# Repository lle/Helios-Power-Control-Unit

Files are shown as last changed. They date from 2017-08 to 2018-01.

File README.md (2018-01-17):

# Helios Makerspace - PCU: Power Control Unit

## Short Description
Device that request a keycode from the user in order to power-up a tool in a Makerspace  
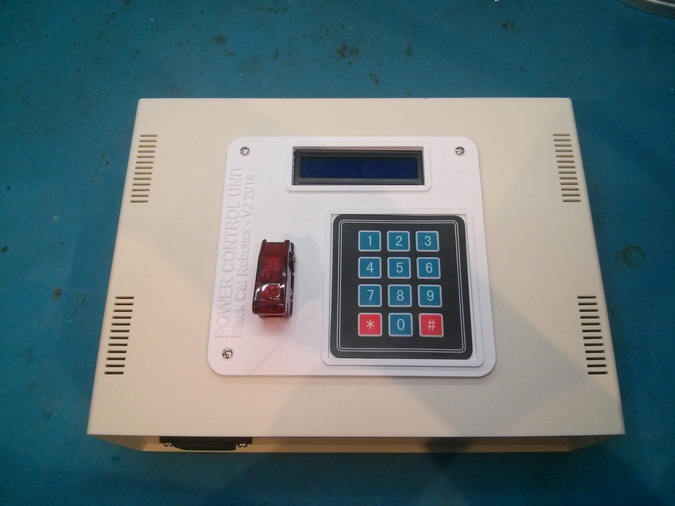
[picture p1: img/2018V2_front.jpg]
Helios PCU


## Demonstration
https://www.youtube.com/watch?v=vD_NKFLX1eg

## Problem Statement
At Helios Makerspace, there is a number of dangerous tools (ei: CNC, table saws, metal lathe). Members should always the staff if they can use the machine. 

## Creating the PCU
The power control unit locks the power from a tool until the correct password has been inputted. Furthermore, the administrator can set timeouts amount between 15 minutes and 2 hours. When the timeout has been reached, the PCU will produce several waves of warning beep at 60, 30 and 10 seconds, before shutting down.

## About Version 2 (2018 Model)
At the beginning of 2018, a version #2 has been produced. It has 4 minor but important upgrade
* LCD screen is on the I2C line of the Arduino
* 2 different passwords: user password + admin password
* wiring have been crimped and shrink-wrapped
* a NEMA15 female socket has been added

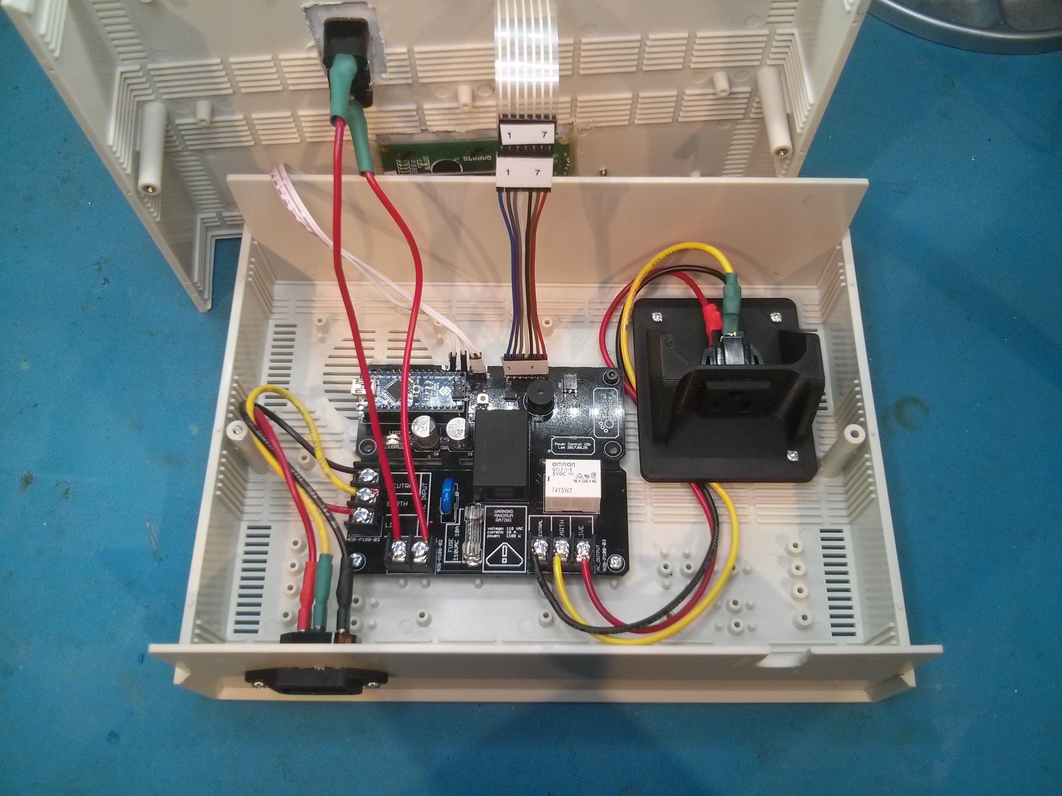
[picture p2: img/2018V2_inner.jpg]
Version 2


#### Close up of LCD I2C Connector
The LCD I2C module has 4 pins (SDA, SCL, GND, +5V). So it has been labelled "D, C, -, +"
The connector labelle "1  7" is for the keypad. The connector has been labelled to avoid placing the cable reversed.
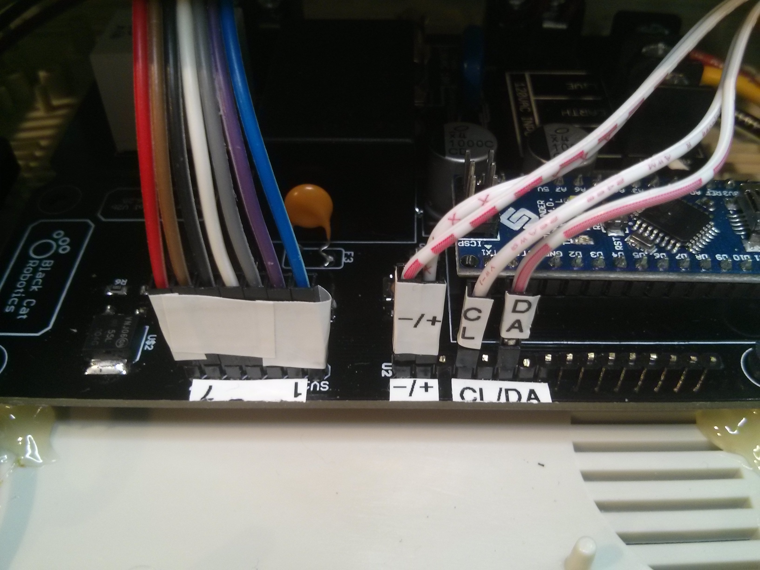
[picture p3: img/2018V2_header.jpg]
Header

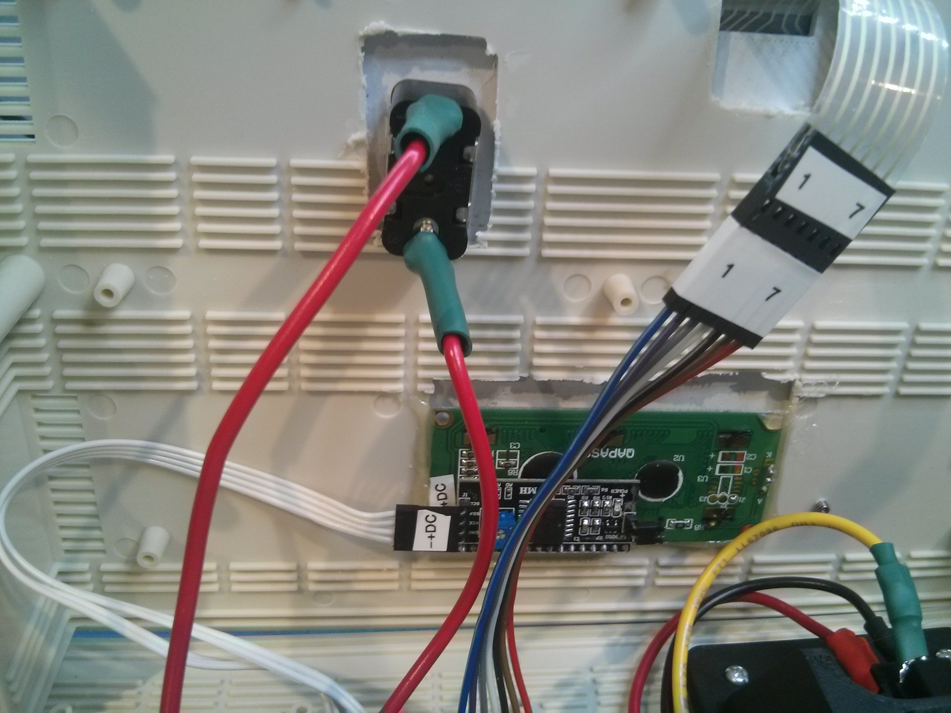
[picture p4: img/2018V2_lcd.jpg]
LCD
a

#### Close up of NEMA15 socket
A custom 3D printing part has been produced to allow the installation of the panel-mount socket. The model is available for download in the "mechanical" folder
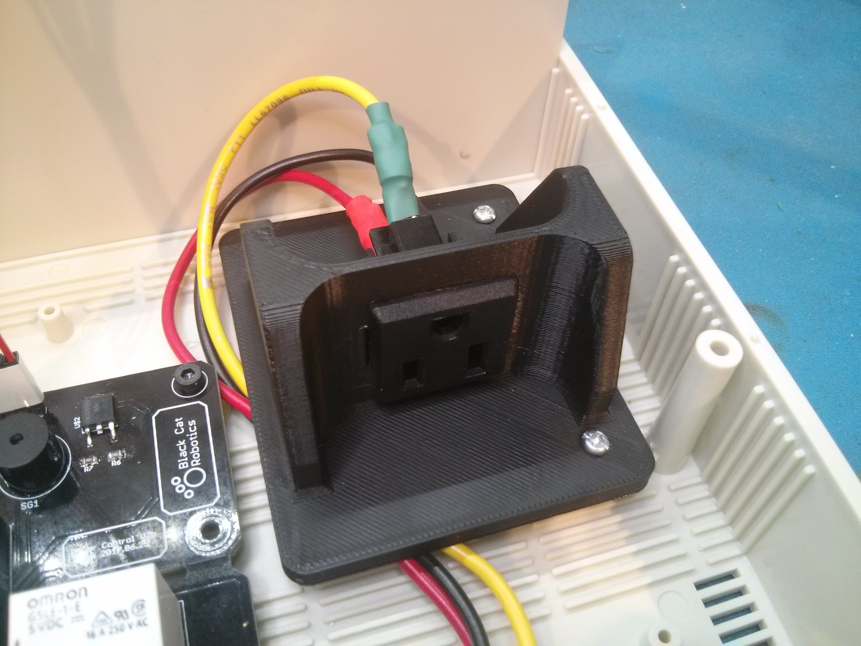
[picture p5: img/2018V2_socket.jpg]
Socket


#### Close up of the wrapped crimpped cable
The cables are first crimpped and then heat-shrink are used to isolate the exposed metal part of the quick-connect.
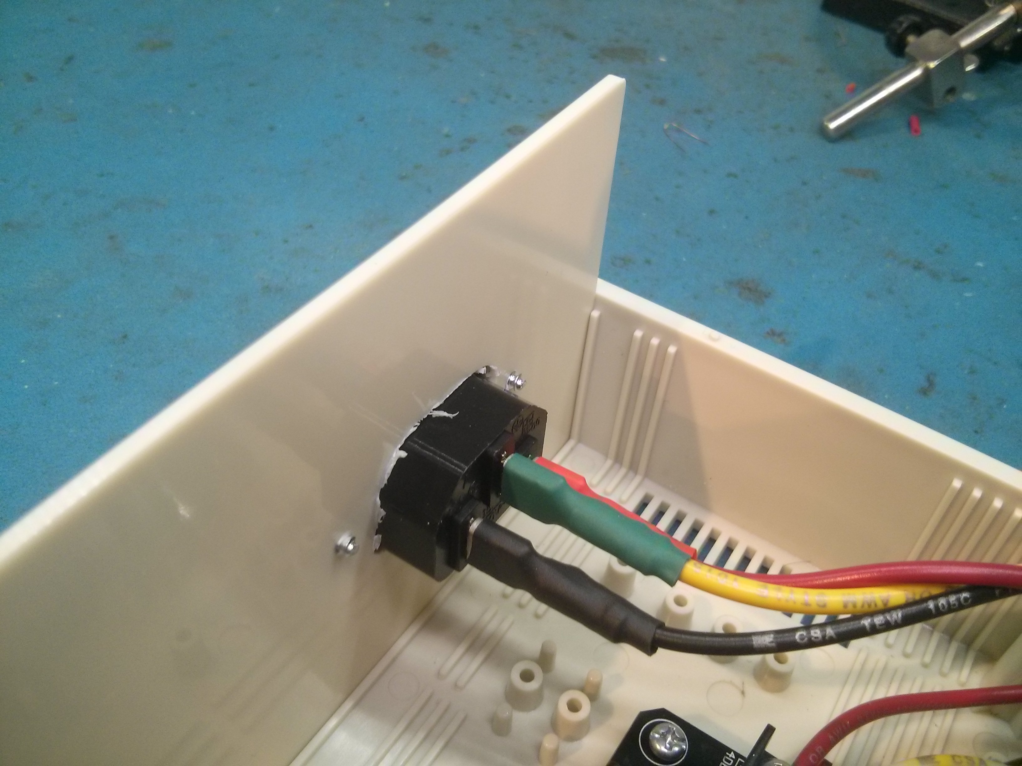
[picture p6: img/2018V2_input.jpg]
Crimpped


## Limitations
The current board design only support devices lower than 10 amps at constant current due to the PCB trace width.
Assuming the PCB is 1oz/ft^2, at 10A and trace width of 180 mils the PCB temperature will raise by 21 degrees celcius. I wasn't confortable allowing the PCB to raise too much.
If you wanted to have a PCB that supports 15A, you would need to manufacture a PCB at 2oz/ft^2. 
* Beware: if you manufacture a PCB for 15A, change the fuse+fuse clip. They are only rated for 10A 

## Known Issues
### Relay flicker on boot-up
On boot-up the Arduino will turn on pin D13 and consequently turn on the relay for a breif moment. That is un-safe for the purpose of this device. This is caused by the Arduino bootloader which raises the LED pin HIGH during boot. We have to make this project as portable as possible, so instead of touching the bootloader and asking everybody to reflash their arduino, I'm just going to issue a new PCB design which uses pin D12 for the relay.

### Hardware Patch
To fix this problem on the first manufactured PCB, we can bypass the relay into pin D12 instead of D13.
* First cut the D13 pin off the Arduino Nano
* Then, on the bottom of the PCB, solder a bypass wire to connect D13 to D12
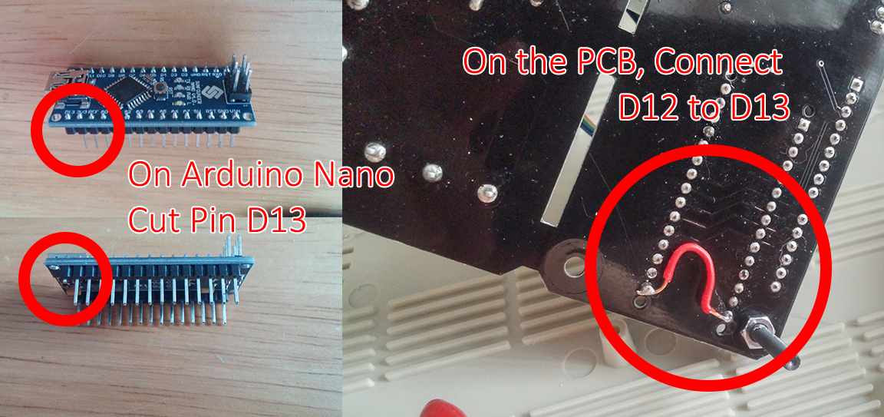
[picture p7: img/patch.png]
Relay Flicker Patch


## BOM
| Digikey | | | | | |
|---|---|---|---|---|---|
| Quantity | Part Number | Description | Comment | Unit Price CAD | Sub Total |
| 1 | Z2616-ND | RELAY GEN PURPOSE SPDT 16A 5V | | 3.06 | 3.06 |
| 10 | 311-3454-1-ND | CAP CER 1UF 25V X7R 1206 | | 0.137 | 1.37 |
| 1 | NTD3055L104T4GOSCT-ND | MOSFET N-CH 60V 12A DPAK | | 0.95 | 0.95 |
| 10 | 311-100KCRCT-ND | RES SMD 100K OHM 1% 1/8W 0805 | | 0.031 | 0.31 |
| 10 | 311-10.0CRCT-ND | RES SMD 10 OHM 1% 1/8W 0805 | | 0.031 | 0.31 |
| 10 | RMCF0805JT150RCT-ND | RES SMD 150 OHM 5% 1/8W 0805 | | 0.024 | 0.24 |
| 10 | RMCF0805JT470RCT-ND | RES SMD 470 OHM 5% 1/8W 0805 | | 0.024 | 0.24 |
| 1 | 732-4988-1-ND | LED AMBER CLEAR 1206 SMD | | 0.27 | 0.27 |
| 1 | 732-5032-1-ND | LED GREEN CLEAR 1206 SMD | | 0.24 | 0.24 |
| 1 | 668-1458-ND | AUDIO MAGNETIC INDICATOR 4-7V TH | | 2.16 | 2.16 |
| 1 | A98472-ND | CONN BARRIER STRIP 2CIRC 0.325" | | 1.33 | 1.33 |
| 1 | A98473-ND | CONN BARRIER STRIP 3CIRC 0.325" | | 1.52 | 1.52 |
| 2 | 486-2019-ND | FUSE CLIP CARTRIDGE 10A PCB | WARNING 10A ONLY | 0.14 | 0.28 |
| 1 | RXEF050-2HFCT-ND | PTC RESET FUSE 72V 500MA RADIAL | | 0.62 | 0.62 |
| 2 | 493-14520-1-ND | CAP ALUM 1000UF 20% 16V SMD | | 1.3 | 2.6 |
| 1 | F1728-ND | FUSE GLASS 15A 250VAC 5X20MM | | 0.46 | 0.46 |
| 1 | SMBJ7.0A-FDICT-ND | TVS DIODE 7VWM 12VC SMB | | 0.6 | 0.6 |
| 1 | 102-2589-ND | POWER SUPPLY SWITCHING 5V 2W | | 17.78 | 17.78 |
| 1 | 495-6464-ND | VARISTOR DISC 14MM | | 0.74 | 0.74 |
| 1 | 3314J-2-103ECT-ND | TRIMMER 10K OHM 0.25W SMD | | 3.12 | 3.12 |
| 1 | Q212-ND | PWR ENT RCPT IEC320-C14 | | 1.13 | 1.13 |
| 1 | Q337-ND | PWR ENT RCPT NEMA5-15 PANEL | | 1.13 | 1.13 |
| | | | | | |
| Other Stores | | | | | |
| Quantity | Description | URL | Customer Reference | Unit Price CAD | Sub Total |
| 1 | Project Box | https://addison-electronique.com/boitier-abs-257-x-190-x-82-mm.html | | 13.99 | 13.99 |
| 1 | Extension Cord | https://addison-electronique.com/rallonge-electrique-16-3-sjtw-1-metre.html | | 2.99 | 2.99 |
| 1 | Switch | https://addison-electronique.com/interrupteur-a-levier-on-off-7807.html | | 1.99 | 1.99 |
| 1 | Switch Cover | https://addison-electronique.com/couvert-pour-interrupteur-a-levier-vert-clair.html | | 0.99 | 0.99 |
| | | | | | |
| 1 | LCD | http://bit.ly/2vsK9xS | | 2.49 | 2.49 |
| 1 | Keypad | http://bit.ly/2wrNNMV | | 1.60 | 1.60 |
| | | | | | |
| 1 | Arduino Nano | https://www.sunfounder.com/board/arduino/nano.html | | 13.94 | 13.94 |
| | | | | | |

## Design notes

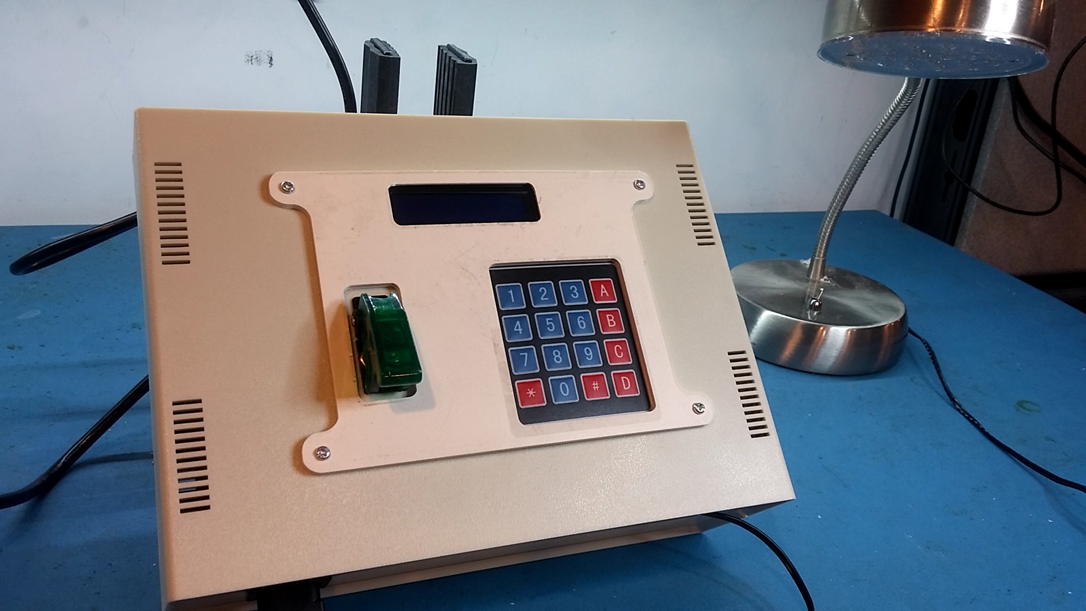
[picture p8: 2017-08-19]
img/heliosPCU.png

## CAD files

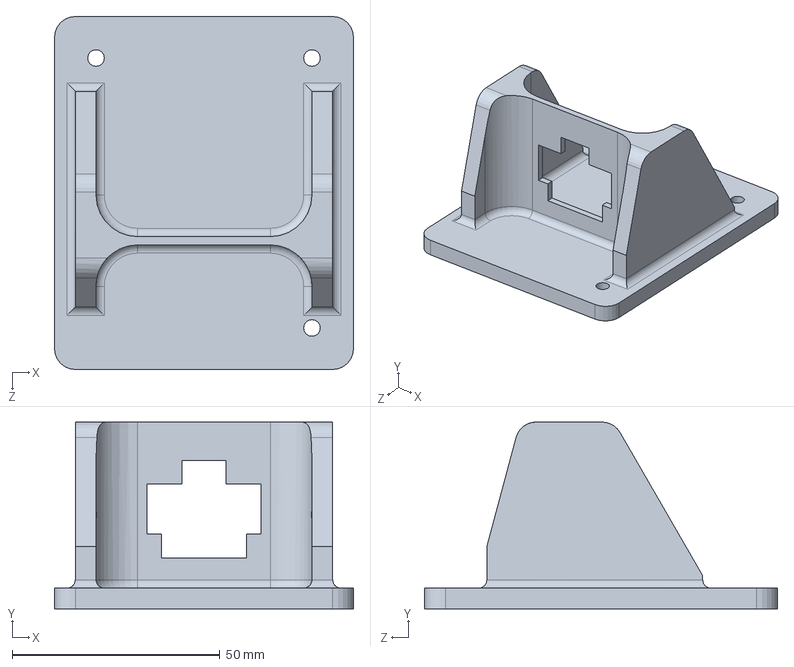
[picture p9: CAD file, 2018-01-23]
Mechanical/2018-01-16_outletSocket_holder_V2.SLDPRT
72.0 x 45.0 x 85.0 mm

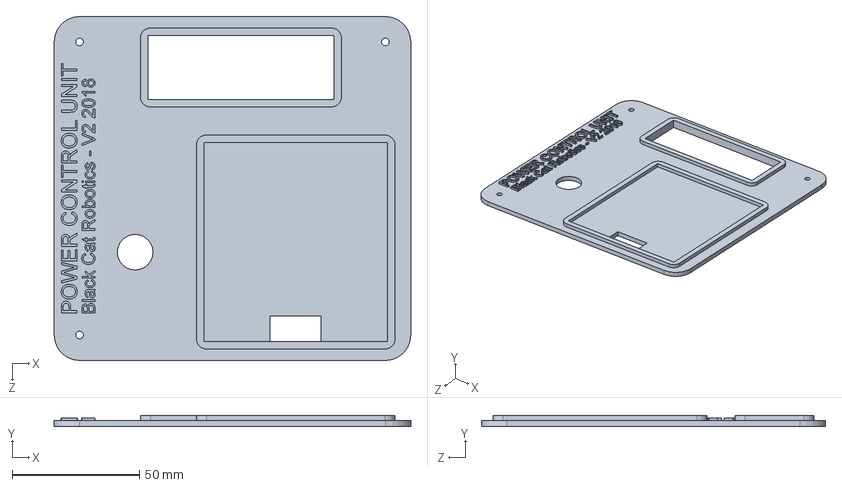
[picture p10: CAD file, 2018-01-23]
Mechanical/2018-01-06_enclosure_top_V2.SLDPRT
140.0 x 4.50 x 135.0 mm

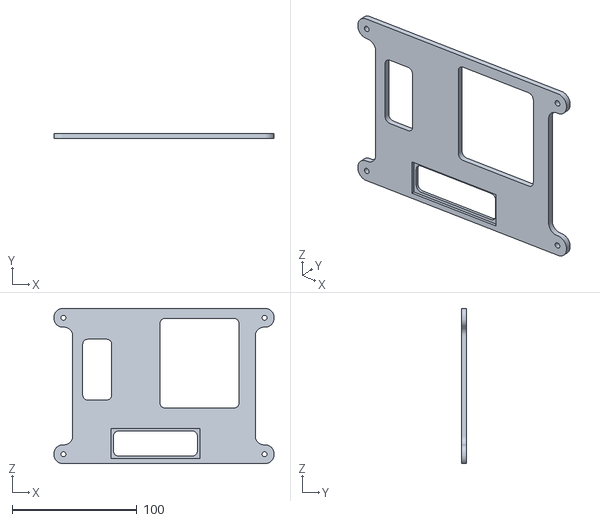
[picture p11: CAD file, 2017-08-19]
Mechanical/2017-08-14_frame3b.STL
176.2 x 4.00 x 124.2

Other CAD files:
Mechanical/2017-08-14_frame.SLDPRT
Mechanical/2018-01-06_enclosure_top_V2.STL
Mechanical/2018-01-16_outletSocket_holder_V2.STL

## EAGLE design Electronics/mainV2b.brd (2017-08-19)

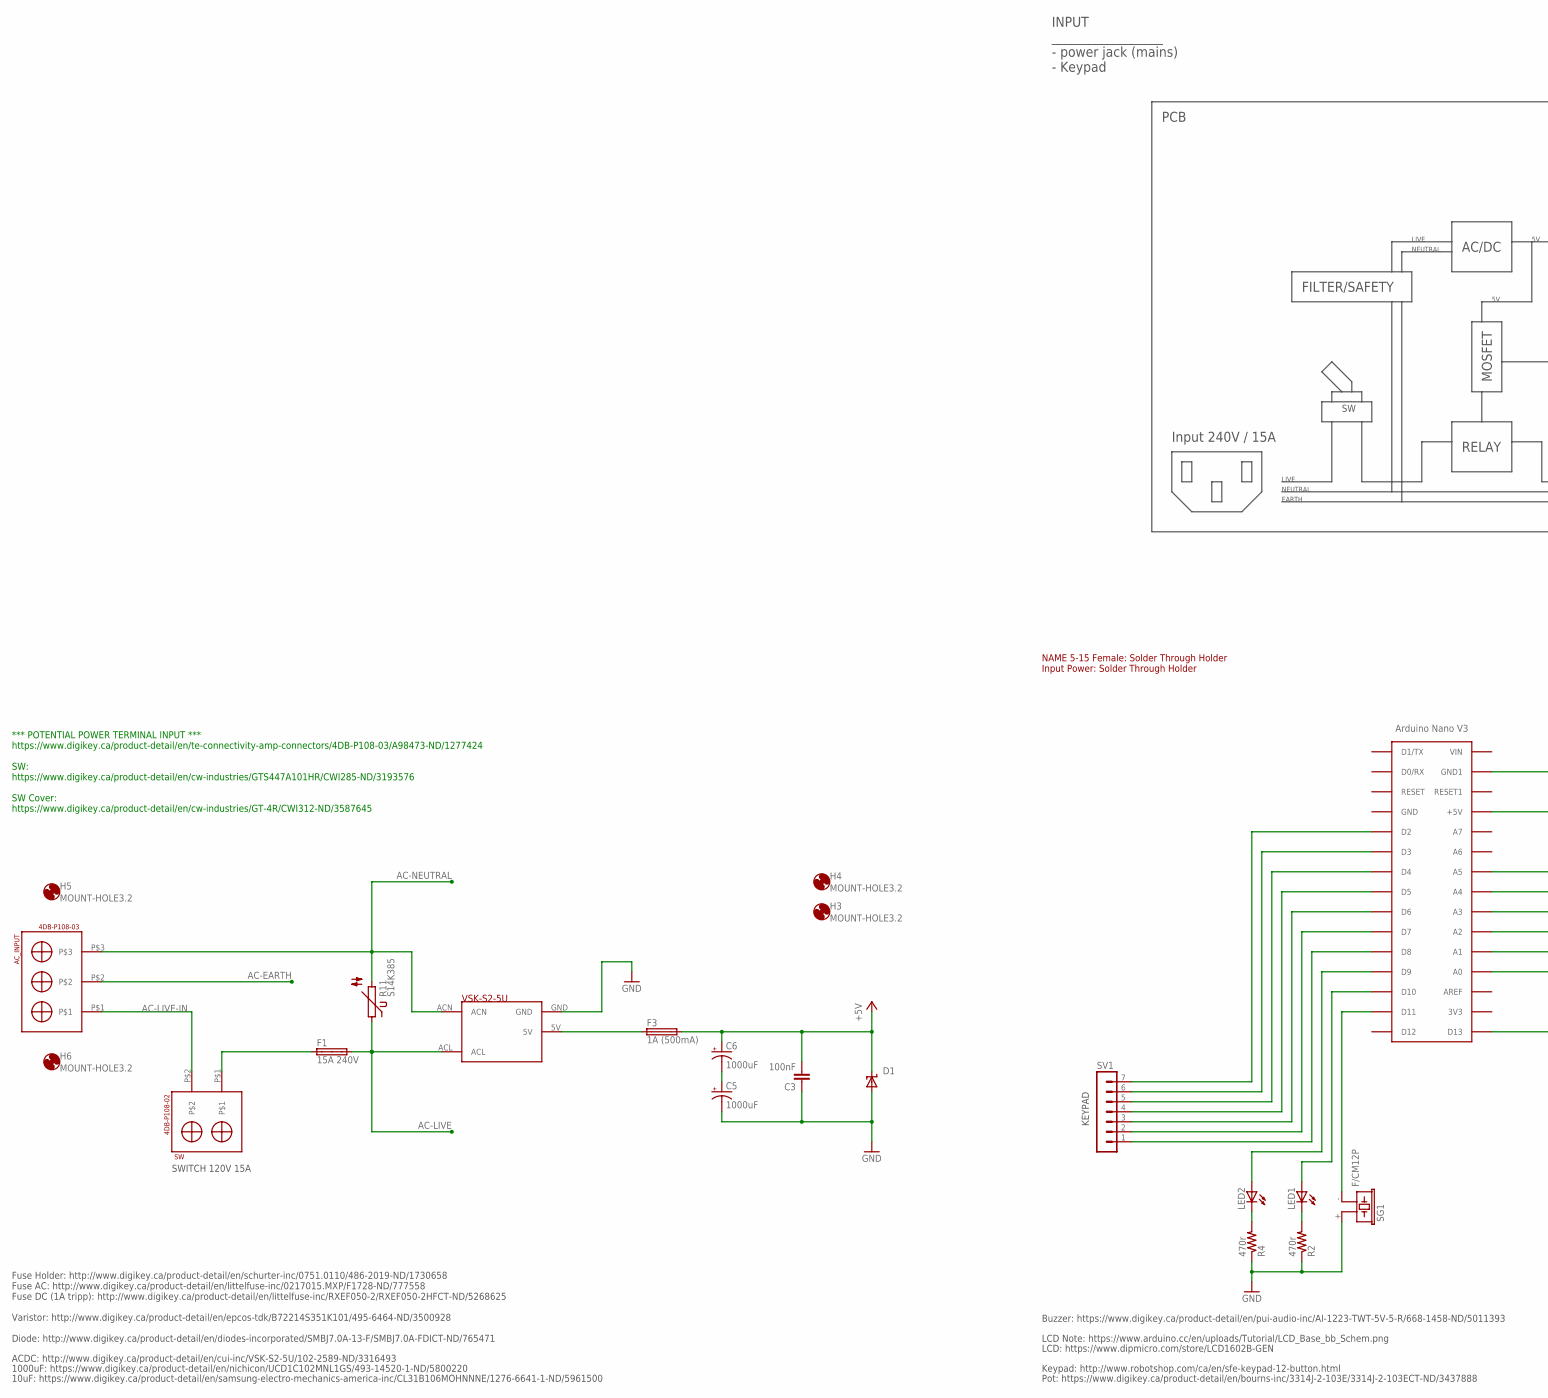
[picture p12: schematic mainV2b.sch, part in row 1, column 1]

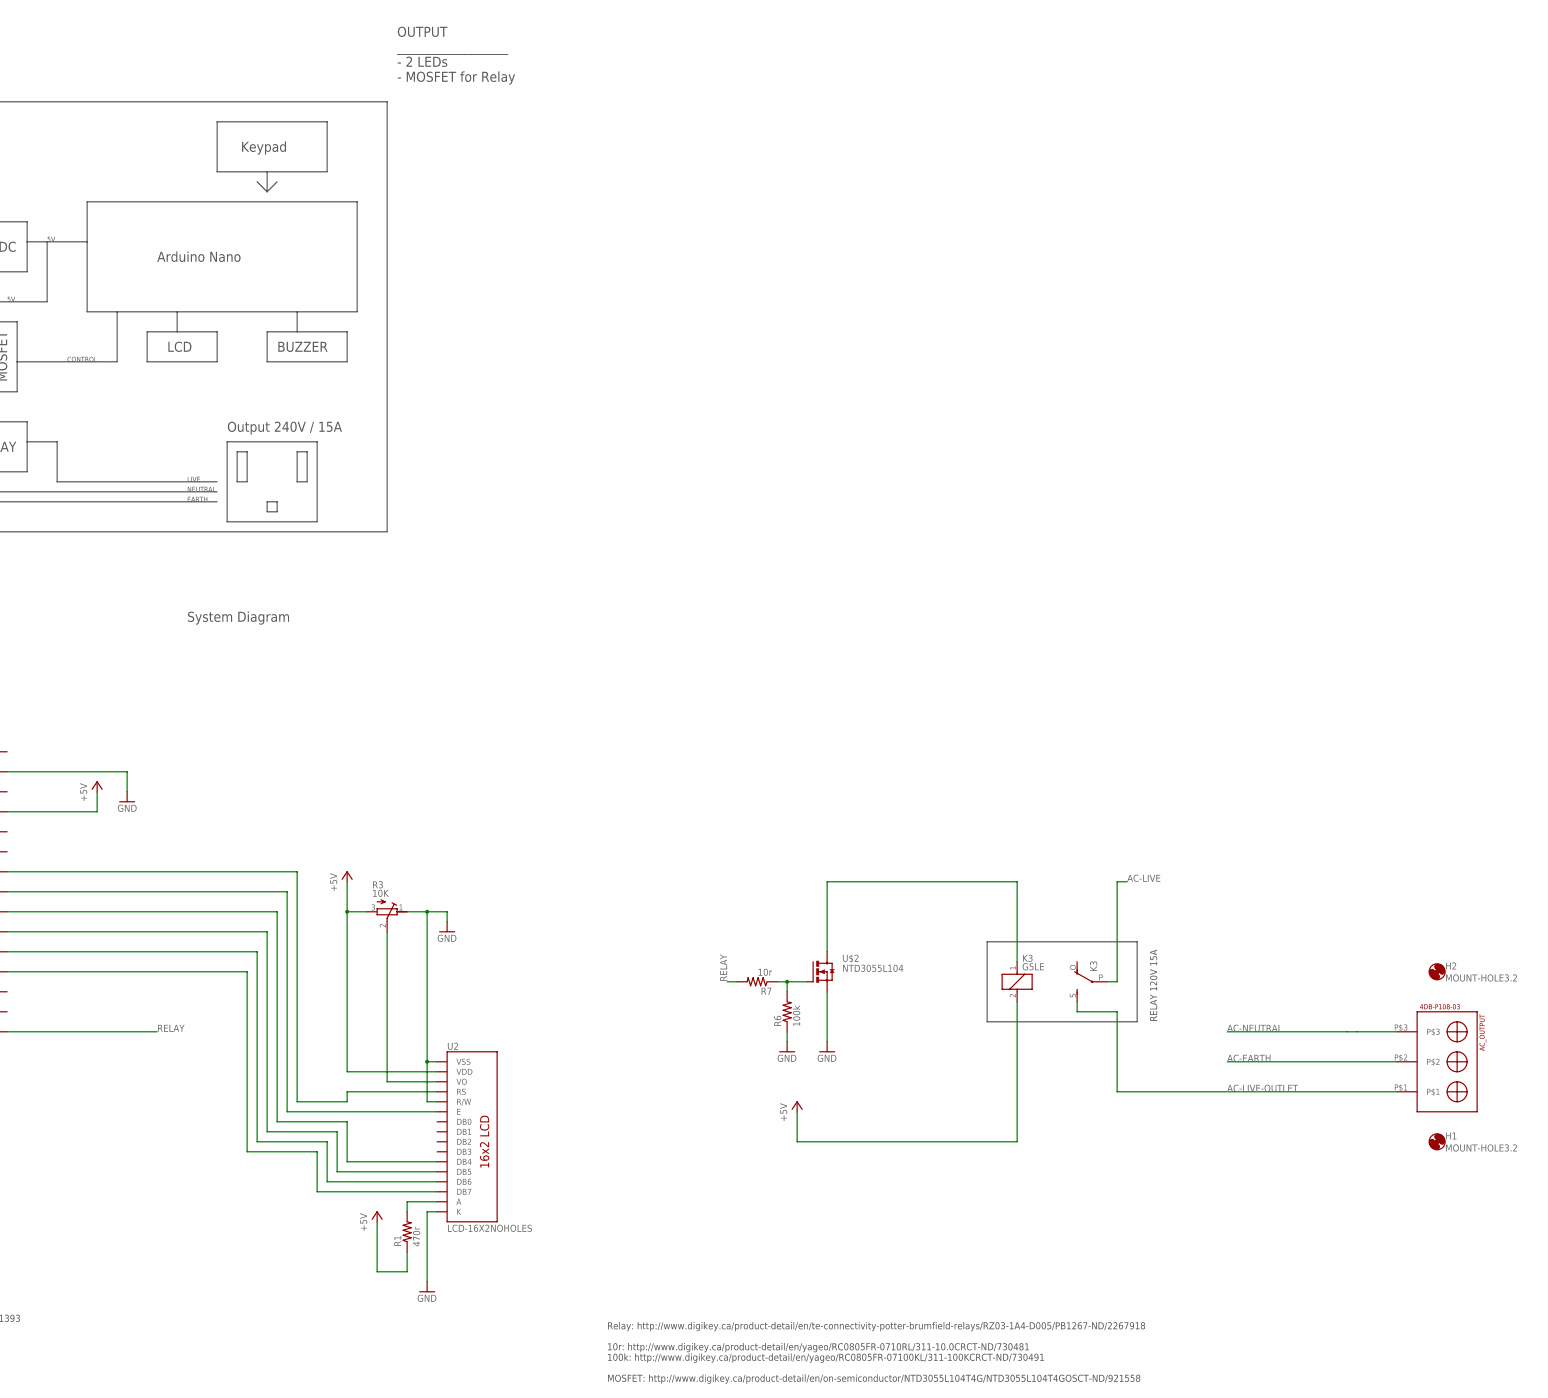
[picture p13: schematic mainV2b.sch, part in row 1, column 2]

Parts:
AC_INPUT: 4DB-P108-03
AC_OUTPUT: 4DB-P108-03
C3: 100nF; C1206
C5, C6: 1000uF; UD-10X10_NICHICON
D1: SUPPRESSOR-SMBJ; SMBJ
F1: 15A 240V; SHK20L
F3: 1A (500mA); TE5
H1, H2, H3, H4, H5, H6: MOUNT-HOLE3.2; 3,2
K3: G5LE
LED1, LED2: LEDCHIPLED_1206; CHIPLED_1206
R1, R2, R4: 470r; M2012
R3: 10K; RTRIM3314G
R6: 100k; M2012
R7: 10r; M2012
R11: S14K385
SG1: F/CM12P
SV1: MA07-1
SW: 4DB-P108-02
U2: LCD-16X2NOHOLES; LCD-16X2_NOHOLESNOSILK
U$1: ARDUINONANO; PDIP-32
U$2: NTD3055L104; NTDV3055L104
U$4: VSK-2S-5U; VSK-S2-5U

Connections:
+5V: C3.2, C6.+, D1.C, F3.2, K3.2, R1.1, R3.3 (A), U2.2 (VDD), U$1.+5V
AC-EARTH: AC_INPUT.P$2, AC_OUTPUT.P$2
AC-LIVE: F1.2A, K3.P, R11.1, U$4.ACL
AC-LIVE-IN: AC_INPUT.P$1, SW.P$2
AC-LIVE-OUTLET: AC_OUTPUT.P$1, K3.S
AC-NEUTRAL: AC_INPUT.P$3, AC_OUTPUT.P$3, R11.2, U$4.ACN
GND: C3.1, C5.-, D1.A, R2.1, R3.1 (E), R4.1, R6.1, SG1.+ (1), U2.1 (VSS), U2.5 (R/W), U2.16 (K), U$1.GND1, U$2.3 (S), U$4.GND
unnamed: U2.4 (RS), U$1.A2 (A5)
unnamed: U2.6 (E), U$1.A3 (A4)
unnamed: U2.11 (DB4), U$1.A4 (A3)
unnamed: U2.12 (DB5), U$1.A5 (A2)
unnamed: U2.13 (DB6), U$1.A6 (A1)
unnamed: R6.2, R7.1, U$2.1 (G)
unnamed: U2.14 (DB7), U$1.A7 (A0)
unnamed: K3.1, U$2.4 (D)
unnamed: R3.2 (S), U2.3 (VO)
unnamed: R1.2, U2.15 (A)
unnamed: F1.1A, SW.P$1
unnamed: SV1.1, U$1.D8
unnamed: SV1.2, U$1.D7
unnamed: SV1.3, U$1.D6
unnamed: SV1.4, U$1.D5
unnamed: SV1.5, U$1.D4
unnamed: C5.+, C6.-
unnamed: F3.1, U$4.5V
unnamed: SV1.6, U$1.D3
unnamed: SV1.7, U$1.D2
unnamed: LED1.C, R2.2
unnamed: LED2.C, R4.2
unnamed: LED2.A, U$1.D9
unnamed: LED1.A, U$1.D10
unnamed: SG1.- (2), U$1.D11
RELAY: R7.2, U$1.D13

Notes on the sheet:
Relay: http://www.digikey.ca/product-detail/en/te-connectivity-potter-brumfield-relays/RZ03-1A4-D005/PB1267-ND/2267918 10r: http://www.digikey.ca/product-detail/en/yageo/RC0805FR-0710RL/311-10.0CRCT-ND/730481 100k: http://www.digikey.ca/product-detail/en/yageo/RC0805FR-07100KL/311-100KCRCT-ND/73049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
ACDC: http://www.digikey.ca/product-detail/en/cui-inc/VSK-S2-5U/102-2589-ND/3316493
Pot: https://www.digikey.ca/product-detail/en/bourns-inc/3314J-2-103E/3314J-2-103ECT-ND/3437888
1000uF: https://www.digikey.ca/product-detail/en/nichicon/UCD1C102MNL1GS/493-14520-1-ND/5800220
10uF: https://www.digikey.ca/product-detail/en/samsung-electro-mechanics-america-inc/CL31B106MOHNNNE/1276-6641-1-ND/5961500
Fuse Holder: http://www.digikey.ca/product-detail/en/schurter-inc/0751.0110/486-2019-ND/1730658 Fuse AC: http://www.digikey.ca/product-detail/en/littelfuse-inc/0217015.MXP/F1728-ND/777558 Fuse DC (1A tripp): http://www.digikey.ca/product-detail/en/littelfuse-inc/RXEF050-2/RXEF050-2HFCT-ND/5268625 V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
Keypad: http://www.robotshop.com/ca/en/sfe-keypad-12-button.html
LCD Note: https://www.arduino.cc/en/uploads/Tutorial/LCD_Base_bb_Schem.png
LCD: https://www.dipmicro.com/store/LCD1602B-GEN
*** POTENTIAL POWER TERMINAL INPUT *** https://www.digikey.ca/product-detail/en/te-connectivity-amp-connectors/4DB-P108-03/A98473-ND/1277424 SW: https://www.digikey.ca/product-detail/en/cw-industries/GTS447A101HR/CWI285-ND/3193576 SW Cover: https://www.digikey.ca/product-detail/en/cw-industries/GT-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
NAME 5-15 Female: Solder Through Holder Input Power: Solder Through Holder
System Diagram
PCB
Input 240V / 15A
Output 240V / 15A
AC/DC
RELAY
LIVE
NEUTRAL
EARTH
FILTER/SAFETY
Arduino Nano
MOSFET
CONTROL
Keypad
LCD
INPUT __________________ - power jack (mains) - Keypad
OUTPUT __________________ - 2 LEDs - MOSFET for Relay
BUZZER
KEYPAD
Buzzer: https://www.digikey.ca/product-detail/en/pui-audio-inc/AI-1223-TWT-5V-5-R/668-1458-ND/5011393
SWITCH 120V 15A
RELAY 120V 15A

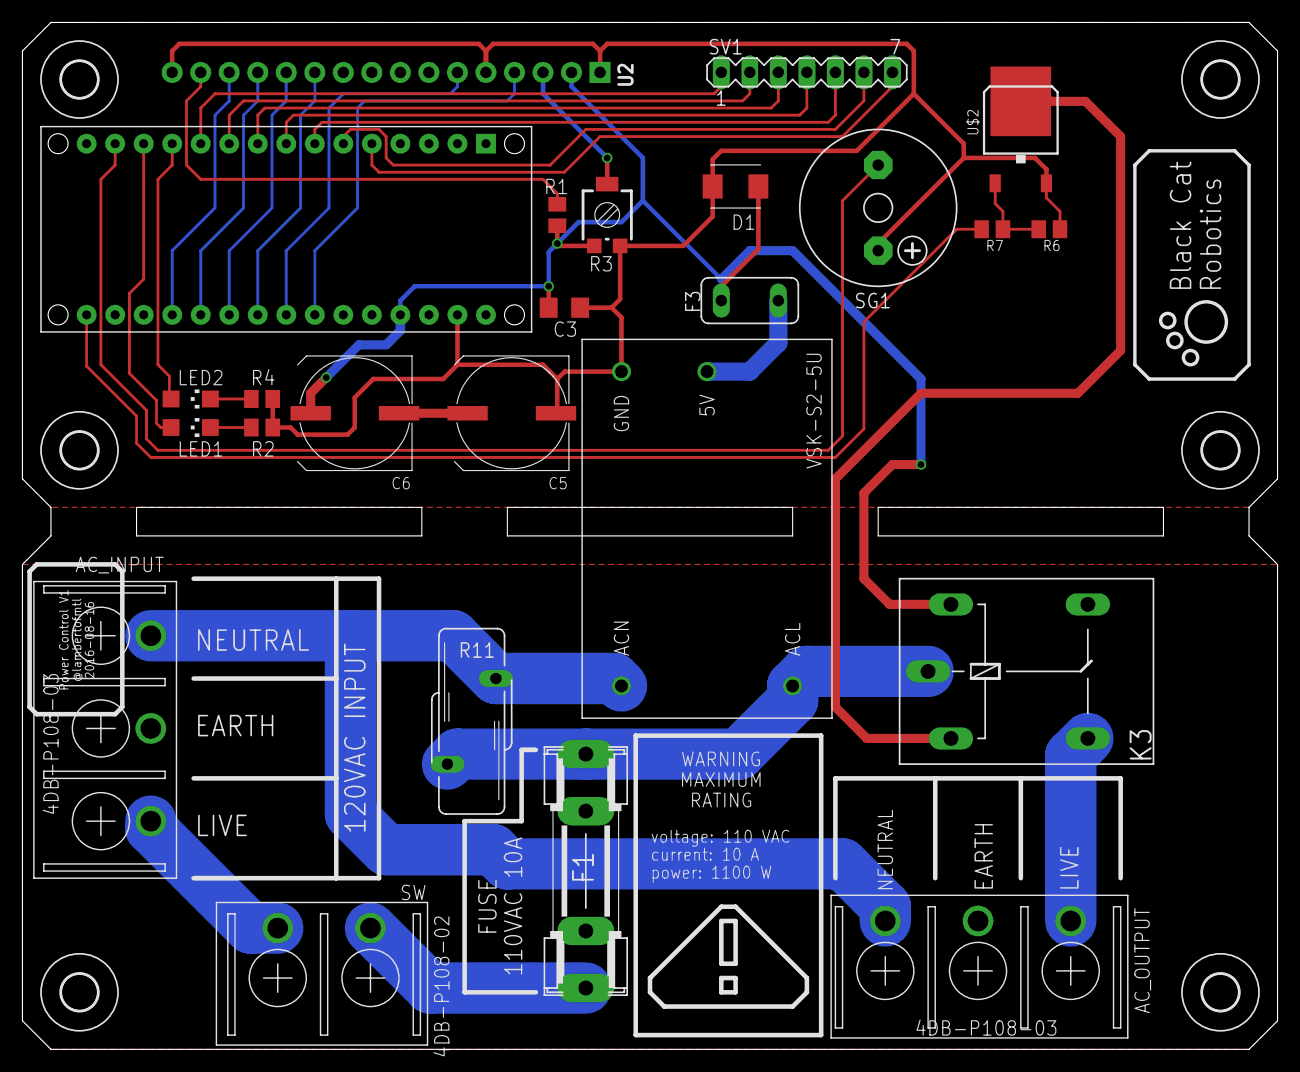
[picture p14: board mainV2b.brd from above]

Board: 2 copper layers, 111.8 x 91.4 mm, 31 parts (0 on the bottom side), 33 nets.

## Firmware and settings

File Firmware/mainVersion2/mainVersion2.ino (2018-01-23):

/*
Keypad: Alexander Brevig (playground.arduino.cc/Code/Keypad)
LiquidCrystal: https://www.sunfounder.com/learn/Sensor-Kit-v2-0-for-Arduino/lesson-1-display-by-i2c-lcd1602-sensor-kit-v2-0-for-arduino.html
Eeprom: Christopher Andrews 2015 (arduino.cc/en/Reference/EEPROM)
*/

#include <Keypad.h>
#include <Wire.h> 
#include <LiquidCrystal_I2C.h>
#include <EEPROM.h>

//define pin
#define BUZZER_PIN 11
#define RELAY_PIN_TYPE1 13
#define RELAY_PIN_TYPE2 12
#define LED_RED_PIN 10
#define LED_GREEN_PIN 9

//define states
#define BUZZER_ON HIGH
#define BUZZER_OFF LOW
#define RELAY_ON HIGH
#define RELAY_OFF LOW

//define state machine
#define STATE_START 1
#define STATE_INPUT 2
#define STATE_PROCESS_PW 3
#define STATE_PW_GOOD 4
#define STATE_PW_BAD 5
#define STATE_ON 6
#define STATE_OFF 7
#define STATE_ADMINLOGIN 8
#define STATE_PROCESS_ADMIN_PW 9
#define STATE_ADMIN_PW_GOOD 10
#define STATE_ADMINMODE 11
#define STATE_NEW_PW 12
#define STATE_NEW_TIMEOUT 13
#define STATE_NEW_ADMIN_PW 14
#define STATE_WAIT_1SEC 99

//LCD Variable
#define LCD_DEFAULT 0
#define LCD_DONE 1

//=========================== Variables =======================
//read from eeprom
uint8_t power_defaultTimeout;
char password_current[5];
char passwordAdmin_current[5];

//user input
char password_enterred[5] = {'-', '-', '-', '-', '-'};
uint8_t password_inputCurrentIndex = 0;
//user menu 
int8_t admin_menuIndex = 0;
int8_t timeout_menuIndex = 0;

//state machine variable
long unsigned int wait_timeStamp = 0;
uint8_t CURRENT_STATE = STATE_START;
uint8_t PENDING_STATE = STATE_START;
uint8_t lcd_updateCompleted = LCD_DEFAULT;
long unsigned int powerOff_countdown_inSeconds;

//buzzer timing variable
uint16_t buzzerSch_numBeep = 0;
uint16_t buzzerSch_intervalBeep = 0;
long unsigned int buzzerSch_startTime = 0;
bool buzzerSch_isCompleted = true;
bool buzzerSch_beepState = BUZZER_OFF;

// LCD INIT 
LiquidCrystal_I2C lcd(0x27,20,4);

// KEYPAD INIT 
const byte ROWS = 4; //four rows
const byte COLS = 3; //three columns
char keys[ROWS][COLS] = {
  {'1','2','3'},
  {'4','5','6'},
  {'7','8','9'},
  {'*','0','#'}
};
byte rowPins[ROWS] = {8, 7, 6, 5}; //connect to the row pinouts of the keypad
byte colPins[COLS] = {4, 3, 2}; //connect to the column pinouts of the keypad
Keypad keypad = Keypad( makeKeymap(keys), rowPins, colPins, ROWS, COLS );


// ********************************** Functions ************************/
void buzzer_setState(uint8_t buzzer_newState)
{
  digitalWrite(BUZZER_PIN, buzzer_newState);
}

void relay_setState(uint8_t relay_newState)
{
  digitalWrite(RELAY_PIN_TYPE1, relay_newState);
  digitalWrite(RELAY_PIN_TYPE2, relay_newState);
}

bool password_addInput(char user_input)
{
  password_enterred[ password_inputCurrentIndex ] = user_input;
  password_inputCurrentIndex++;
  lcd.print( user_input );                                                                //Serial.println( user_input );                            
  if(password_inputCurrentIndex >= 5)
  {
    password_inputCurrentIndex = 0;
    return true;
  }
  else
    return false;
}

void password_clearAll()
{
  for(int i=0; i<5; i++)
  {
    password_enterred[i] = '-';
    lcd.clear();
  }
}

bool password_process()
{
  bool isPassword_good = true;
  for(int i=0; i<5; i++)
  {
    if( password_enterred[i] != password_current[i] )
      isPassword_good = false;
  }
  if( isPassword_good == false )
  {
    password_clearAll();
    return false;
  }
  else
  {
    password_clearAll();
    return true;
  }
}

bool password_admin_process()
{
  bool isPassword_good = true;
  for(int i=0; i<5; i++)
  {
                                                                                                                                //Serial.print(password_enterred[i]); Serial.print(" - "); Serial.println(passwordAdmin_current[i]);
    if( password_enterred[i] != passwordAdmin_current[i] )
      isPassword_good = false;
  }
  if( isPassword_good == false )
  {
    password_clearAll();
    return false;
  }
  else
  {
    password_clearAll();
    return true;
  }
}

void update_userpw()
{
  for(int i=0; i<5; i++)
  {
    EEPROM.write(i, password_enterred[i]);
  }
  lcd.clear(); lcd.setCursor(0,0); lcd.print("User PW Saved"); lcd.setCursor(0,1); lcd.print("Restarting...");                                   //Serial.println("User PW Saved"); Serial.println("Restarting...");   
  buzzer_setState(BUZZER_ON); delay(10); buzzer_setState(BUZZER_OFF);
  delay(2000);
  asm volatile ("  jmp 0"); 
}

void update_adminpw()
{
  for(int i=0; i<5; i++)
  {
    EEPROM.write(i+10, password_enterred[i]);
  }
  lcd.clear(); lcd.setCursor(0,0); lcd.print("Admin PW Saved"); lcd.setCursor(0,1); lcd.print("Restarting...");                                   //Serial.println("Admin PW Saved"); Serial.println("Restarting...");   
  buzzer_setState(BUZZER_ON); delay(10); buzzer_setState(BUZZER_OFF);
  delay(2000);
  asm volatile ("  jmp 0"); 
}

void buzzer_scheduleBeep(uint16_t numBeep, uint16_t intervalBeep)
{
  buzzerSch_numBeep = numBeep * 2; //must be multiplied by 2 since we need 2 stage: ON + OFF
  buzzerSch_intervalBeep = intervalBeep;
  buzzerSch_startTime = millis();
  buzzerSch_isCompleted = false;
}

void buzzer_runSchedule()
{
  if( buzzerSch_isCompleted == false && millis() - buzzerSch_intervalBeep > buzzerSch_startTime)
  {
    buzzerSch_startTime = millis(); //update new start time
    buzzerSch_numBeep--;    //decrement number of beep
    if(buzzerSch_beepState == BUZZER_OFF) 
    { 
      digitalWrite(LED_RED_PIN, HIGH);
      buzzerSch_beepState = BUZZER_ON;
      buzzer_setState(BUZZER_ON);
    }
    else
    {
      digitalWrite(LED_RED_PIN, LOW);
      buzzerSch_beepState = BUZZER_OFF;
      buzzer_setState(BUZZER_OFF);
    }

    //when completed, set everything to off
    if(buzzerSch_numBeep <= 0)
    {
      digitalWrite(LED_RED_PIN, LOW);
      buzzer_setState(BUZZER_OFF);
      buzzerSch_beepState = BUZZER_OFF;
      buzzerSch_numBeep = 0;
      buzzerSch_intervalBeep = 0;
      buzzerSch_isCompleted = true;
    }
  }
}

void timeoutMenu_update(int8_t offset)
{
  timeout_menuIndex = timeout_menuIndex + offset;
  //deal with min/max menu
  if      (timeout_menuIndex<0) { timeout_menuIndex = 5; }
  else if (timeout_menuIndex>5) { timeout_menuIndex = 0; }
  
  //generate menu
  if      (timeout_menuIndex == 0) { lcd.setCursor(0,1); lcd.print("15 minutes    "); }                                 //Serial.println("15 minutes    ");           }
  else if (timeout_menuIndex == 1) { lcd.setCursor(0,1); lcd.print("30 minutes    "); }                                 //Serial.println("30 minutes    ");           }
  else if (timeout_menuIndex == 2) { lcd.setCursor(0,1); lcd.print("45 minutes    "); }                                 //Serial.println("45 minutes    ");           }
  else if (timeout_menuIndex == 3) { lcd.setCursor(0,1); lcd.print("60 minutes    "); }                                 //Serial.println("60 minutes    ");           }
  else if (timeout_menuIndex == 4) { lcd.setCursor(0,1); lcd.print("90 minutes    "); }                                 //Serial.println("90 minutes    ");           }
  else if (timeout_menuIndex == 5) { lcd.setCursor(0,1); lcd.print("120 minutes   "); }                                //Serial.println("120 minutes    ");          }
}

void timeoutMenu_select()
{
  lcd.clear(); lcd.setCursor(0,0); lcd.print("Time Updated"); lcd.setCursor(0,1); lcd.print("Restarting...");
                                                                                                                      //Serial.println("Time Updated"); Serial.println("Restarting...");
  switch(timeout_menuIndex)
  {
    case 0:
      EEPROM.write(5, 15); break;
    case 1:
      EEPROM.write(5, 30); break;
    case 2:
      EEPROM.write(5, 45); break;
    case 3:
      EEPROM.write(5, 60); break;
    case 4:
      EEPROM.write(5, 90); break;
    case 5:
      EEPROM.write(5, 120); break;
  }
  buzzer_setState(BUZZER_ON); delay(10); buzzer_setState(BUZZER_OFF); 
  delay(2000);
  asm volatile ("  jmp 0");       
}

void adminMenu_update(int8_t offset)
{
  admin_menuIndex = admin_menuIndex + offset;
  //deal with min/max menu
  if      (admin_menuIndex<0) { admin_menuIndex = 3; }
  else if (admin_menuIndex>3) { admin_menuIndex = 0; }
  //generate menu
  if      (admin_menuIndex == 0) { lcd.setCursor(0,1); lcd.print("New User PW");      }                                  //Serial.println("New User PW");                         }
  else if (admin_menuIndex == 1) { lcd.setCursor(0,1); lcd.print("New Admin PW");     }                                 //Serial.println("New Admin PW");                         }
  else if (admin_menuIndex == 2) { lcd.setCursor(0,1); lcd.print("Change Timout   "); }                            //Serial.println("Change Timout   ");                         }
  else if (admin_menuIndex == 3) { lcd.setCursor(0,1); lcd.print("Exit            "); }                            //Serial.println("Exit            ");                         }
}

void adminMenu_select()
{
  if(admin_menuIndex == 0)
  {
    lcd.clear(); lcd.setCursor(0,0); lcd.print("Enter New PW:"); lcd.setCursor(0,1);                                    //Serial.println("Enter New PW:");
    CURRENT_STATE = STATE_NEW_PW;
  }
  else if(admin_menuIndex == 1)
  {
    lcd.clear(); lcd.setCursor(0,0); lcd.print("Enter New PW"); lcd.setCursor(0,1);                                     //Serial.println("Enter New PW:");
    CURRENT_STATE = STATE_NEW_ADMIN_PW;
  }
  else if(admin_menuIndex == 2)
  {
    CURRENT_STATE = STATE_NEW_TIMEOUT;
  }
  else if(admin_menuIndex == 3)
  {
    asm volatile ("  jmp 0"); 
  }
}

void lcd_showTimeLeft()
{
  static long unsigned int timeLeft_lastUpdate_timeStamp;
  if( millis() - timeLeft_lastUpdate_timeStamp > 1000) //update every second only
  {
    lcd.setCursor(0,1);
    lcd.print("Time Left: ");                                               //Serial.println("Time Left: ");
    lcd.print(powerOff_countdown_inSeconds);                                //Serial.println(powerOff_countdown_inSeconds);
    lcd.print("  ");                                                        //Serial.println("  ");
                                                                                                
    //warning for timeout
    if(powerOff_countdown_inSeconds == 59) //at 60 seconds
      buzzer_scheduleBeep(2, 100);
    else if(powerOff_countdown_inSeconds == 30)
      buzzer_scheduleBeep(3, 100);
    else if(powerOff_countdown_inSeconds == 15)
      buzzer_scheduleBeep(6, 50);
    else if(powerOff_countdown_inSeconds >= 1 && powerOff_countdown_inSeconds < 10)
      buzzer_scheduleBeep(1, 20);
    else if(powerOff_countdown_inSeconds == 0)
      CURRENT_STATE = STATE_OFF;

    powerOff_countdown_inSeconds--;
    timeLeft_lastUpdate_timeStamp = millis();
  }
}

void firstRun()
{
  EEPROM.write(0, '1'); //password characters
  EEPROM.write(1, '2');
  EEPROM.write(2, '3');
  EEPROM.write(3, '4');
  EEPROM.write(4, '5');
  
  EEPROM.write(5, 60); //default timeout = 60

  EEPROM.write(10, '0');
  EEPROM.write(11, '0');
  EEPROM.write(12, '0');
  EEPROM.write(13, '0');
  EEPROM.write(14, '0');
}

// ********************************** SETUP *********************/
void setup()
{  
  /***************************
  If this is the first time you are running the code, 
  run the function firstRun() to flash the EEPROM with the default password "12345" 
  and default timeout =  60 minutes
  */
  /***************************/
  firstRun();
  /***************************/

                                                                                            //Serial.begin(9600);

  //load user password
  for(int i=0; i<5; i++)
  {
    password_current[i] = EEPROM.read(i);     //load stored password
                                                                                            //Serial.print(password_current[i]);
  }
                                                                                            //Serial.println("");
  
  //load timeout
  power_defaultTimeout = EEPROM.read(5);
                                                                                            //Serial.print(power_defaultTimeout);
                                                                                            //Serial.println("");

  //load admin password
  for(int i=0; i<5; i++)
  {
    passwordAdmin_current[i] = EEPROM.read(i+10);
                                                                                            //Serial.print(passwordAdmin_current[i]);
  }
                                                                                            //Serial.println("");
  
  pinMode(LED_GREEN_PIN, OUTPUT); //LED 2
  pinMode(LED_RED_PIN, OUTPUT);   //LED 1
  pinMode(BUZZER_PIN, OUTPUT);    //Buzzer
  pinMode(RELAY_PIN_TYPE1, OUTPUT);     //Relay
  pinMode(RELAY_PIN_TYPE2, OUTPUT);     //Relay

  digitalWrite(LED_RED_PIN, HIGH);      
  digitalWrite(LED_GREEN_PIN, HIGH);
  delay(50);
  buzzer_setState(BUZZER_ON);           //Then Buzz
  delay(50);
  buzzer_setState(BUZZER_OFF);          //Then Flash Green
  delay(50);
  digitalWrite(LED_GREEN_PIN, LOW);
  digitalWrite(LED_RED_PIN, LOW);
  

                                                                            
  
  //Init LCD Init
  lcd.init();                      // initialize the lcd 
  lcd.init();
  // Print a message to the LCD.
  lcd.backlight();
  lcd.setCursor(0,0);
  lcd.print("Loading");                                                     //Serial.println("Loading");
  lcd.setCursor(0,1);
  for(int i=0; i<16; i++)
  {
    lcd.print(char(255));                                                   //Serial.println(char(255));
    delay(5);
  }
  delay(500);

  //Introduction
  lcd.clear();
  lcd.setCursor(0, 0);
  lcd.print("Helios Machine");                                              //Serial.println("Helios Machine");
  lcd.setCursor(0, 1);
  lcd.print("Control - V1.0");                                              //Serial.println("Control - V1.0");
  delay(1000);

  lcd.clear();
  lcd.setCursor(0, 0);
  lcd.print("by   Black Cat");                                              //Serial.println("by   Black Cat");
  lcd.setCursor(0, 1);
  lcd.print("     Robotics");                                               //Serial.println("     Robotics");
  delay(1000);
}



// ********************************** MAIN LOOP *********************/
void loop()
{
  char key;
  bool diuUser_input_fiveNumber;
  bool isPasswordCorrect;

  buzzer_runSchedule();

  //STATE MACHINE
  switch(CURRENT_STATE)
  {
    case STATE_START:
      //Execution
      lcd.clear(); lcd.setCursor(0,0); lcd.print("Enter Password");                                                           //Serial.println("Enter Password");
      CURRENT_STATE = STATE_INPUT;
      lcd.setCursor(0,1);
      break;
      
    case STATE_INPUT:
      //Execution
      key = keypad.getKey();
      diuUser_input_fiveNumber = false;
      if(key) 
      { 
        if(key=='*' && password_inputCurrentIndex == 0)
        {
          lcd.clear(); lcd.setCursor(0,0); lcd.print("Admin Login"); lcd.setCursor(0,1); lcd.print("PW:");                    //Serial.println("Admin Login"); Serial.println("PW:");
          CURRENT_STATE = STATE_ADMINLOGIN;
          buzzer_scheduleBeep(3, 75);
        }
        else
        {
          diuUser_input_fiveNumber = password_addInput(key); 
          buzzer_scheduleBeep(1, 10);
        }
      }
      //Transition Out
      if( diuUser_input_fiveNumber == true )
        CURRENT_STATE = STATE_PROCESS_PW;
      break;

    case STATE_ADMINLOGIN:
      //Execution
      key = keypad.getKey();
      diuUser_input_fiveNumber = false;
      if(key) 
      { 
        diuUser_input_fiveNumber = password_addInput(key); 
        buzzer_scheduleBeep(1, 10);
      }
      //Transition Out
      if( diuUser_input_fiveNumber == true )
        CURRENT_STATE = STATE_PROCESS_ADMIN_PW;
      break;

    case STATE_PROCESS_PW:
      //Execution
      isPasswordCorrect = false;
      isPasswordCorrect = password_process();
      //Transition Out
      if( isPasswordCorrect == true )
      {
        CURRENT_STATE = STATE_PW_GOOD;
        digitalWrite(LED_GREEN_PIN, HIGH);
      }
      else
        CURRENT_STATE = STATE_PW_BAD;
      break;

    case STATE_PROCESS_ADMIN_PW:
      //Execution
      isPasswordCorrect = false;
      isPasswordCorrect = password_admin_process();
      //Transition Out
      if( isPasswordCorrect == true )
        CURRENT_STATE = STATE_ADMIN_PW_GOOD;
      else
        CURRENT_STATE = STATE_PW_BAD;
      break;

    case STATE_PW_GOOD:
      //Execution
      lcd.clear(); lcd.setCursor(0,0); lcd.print("Password OK"); lcd.setCursor(0,1); lcd.print("Powering On");                                        //Serial.println("Password OK");  Serial.println("Powering On");
      relay_setState(RELAY_ON);
      digitalWrite(LED_GREEN_PIN, LOW);
      buzzer_scheduleBeep(2, 50);
      powerOff_countdown_inSeconds = power_defaultTimeout * 60; //defaultTimeOut(minutes) x 60(sec) = total seconds timeout
      //wait state
      wait_timeStamp = millis();
      PENDING_STATE = STATE_ON;
      CURRENT_STATE = STATE_WAIT_1SEC;
      break;

    case STATE_ADMIN_PW_GOOD:
      //Execution
      lcd.clear(); lcd.setCursor(0,0); lcd.print("Password OK"); lcd.setCursor(0,1); lcd.print("Admin Mode");                                         //Serial.println("Password OK");  Serial.println("Admin Mode");
      buzzer_scheduleBeep(2, 50);
      //wait state
      wait_timeStamp = millis();
      PENDING_STATE = STATE_ADMINMODE;
      CURRENT_STATE = STATE_WAIT_1SEC;
      break;

    case STATE_ADMINMODE:
      //Execution
      if(lcd_updateCompleted != LCD_DONE)
      {
        lcd_updateCompleted = LCD_DONE;
        lcd.clear(); lcd.setCursor(0,0); lcd.print("<- *  MENU  # ->");                                                                               //Serial.println("<- *  MENU  # ->");
        adminMenu_update(0); 
      }
      key = keypad.getKey();
      if(key) //de-bouncer
      {
        //Transition Out
        if( key == '#' )
        {
          adminMenu_update(1); 
          buzzer_scheduleBeep(1, 10); 
        }
        else if( key == '*' )
        {
          adminMenu_update(-1);
          buzzer_scheduleBeep(1, 10);
        }
        else if( key == '0' )
        {
          adminMenu_select();
          buzzer_scheduleBeep(1, 10);
          lcd_updateCompleted = LCD_DEFAULT;
        }
      }
      break;
    
    case STATE_PW_BAD:
      //Execution
      lcd.clear(); lcd.setCursor(0,0); lcd.print("Bad Password");                                                                                      //Serial.println("Bad Password");
      relay_setState(RELAY_OFF);
      buzzer_scheduleBeep(5, 50);
      //wait state
      wait_timeStamp = millis();
      PENDING_STATE = STATE_START;
      CURRENT_STATE = STATE_WAIT_1SEC;
      break;

    case STATE_ON:
      //Execution
      if(lcd_updateCompleted != LCD_DONE)
      {
        lcd_updateCompleted = LCD_DONE;
        lcd.clear(); lcd.setCursor(0,0); lcd.print("# to Shutdown"); lcd.setCursor(0,1);                                                               //Serial.println("# to Shutdown"); 
      }
      lcd_showTimeLeft();
      key = keypad.getKey();
      if(key) //de-bouncer
      {
        //Transition Out
        if( key == '#' ) 
        {
          lcd_updateCompleted = LCD_DEFAULT;
          CURRENT_STATE = STATE_OFF; 
        }
      }
      break;

    case STATE_OFF:
      //Execution
      lcd.clear(); lcd.setCursor(0,0); lcd.print("Power Off");                                                                                          //Serial.println("Power Off");
      relay_setState(RELAY_OFF);
      digitalWrite(LED_GREEN_PIN, LOW);
      buzzer_scheduleBeep(2, 50);
      //go into wait state
      wait_timeStamp = millis();
      PENDING_STATE = STATE_START;
      CURRENT_STATE = STATE_WAIT_1SEC;
      break;

    case STATE_WAIT_1SEC: /* NON LOCKING DELAY */
      if(millis() - wait_timeStamp > 2000)
      {
        CURRENT_STATE = PENDING_STATE;
      }
      break;

    case STATE_NEW_PW:
      //Execution
      key = keypad.getKey();
      diuUser_input_fiveNumber = false;
      if(key) 
      { 
        if(key=='*' || key=='#')
        {
          lcd.clear(); lcd.setCursor(0,0); lcd.print("Cancelled");                                                                                     //Serial.println("Cancelled"); 
          buzzer_setState(BUZZER_ON); delay(10); buzzer_setState(BUZZER_OFF);
          delay(2000);
          asm volatile ("  jmp 0"); 
        }
        else
        {
          diuUser_input_fiveNumber = password_addInput(key); 
          buzzer_scheduleBeep(1, 10);
        }
      }
      //Transition Out
      if( diuUser_input_fiveNumber == true )
        update_userpw();
      break;
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

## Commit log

2017-08-19 Push all the files
    [frame.SLDPRT, frame3b.STL, mainV1_BOM.xlsx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]
2017-08-19 added new updated BOM
    [BOM.xlsx, mainV1_BOM.xlsx]
2017-08-19 correct BOM mistake
2017-08-19 Hardware Patch
    Since Pin D13 is raised HIGH during bootup due to the arduino bootloader, the relay turns on for a brief moment during boot-up. This is unsafe for the purpose of this device.
    So the relay control pin was moved from D13 to D12. Picture of the hardware patch has been included in the github readme
2017-08-19 Included instruction for Hardware Patch
    On boot-up the Arduino will turn on pin D13 and consequently turn on the relay for a breif moment. That is un-safe for the purpose of Tthis device.
    To fix this problem on the first manufactured PCB, we can bypass the relay into pin D12 instead of D13.
2017-08-21 Added Arduino
    Added Arduino
2018-01-23 Updated missing files for V2
    Added folder for V2 firmware
    Added Mechanical parts that were 3D printed
    [2017-08-14_frame.SLDPRT, 2017-08-14_frame3b.STL, 2018-01-06_enclosure_top_V2.SLDPRT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]

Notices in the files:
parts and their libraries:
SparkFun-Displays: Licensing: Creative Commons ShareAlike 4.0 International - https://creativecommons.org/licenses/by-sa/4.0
